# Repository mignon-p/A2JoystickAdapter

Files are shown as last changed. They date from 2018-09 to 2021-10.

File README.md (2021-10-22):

# Apple II Joystick Adapter

This small board lets you plug a 16-pin joystick into the external
9-pin joystick port on the Apple IIe.  Although the Apple IIe has an
internal 16-pin joystick port, I found that the connector on my
joystick was too big to fit through any of the holes on the back of
the IIe.  So, I created this adapter to let me plug it in externally.

This adapter could also be useful for the Apple IIc, which does not
have a 16-pin joystick port at all, although I have not tested it on a
IIc.

* [View schematic](doc/schematic.pdf)
* [View PCB][41]

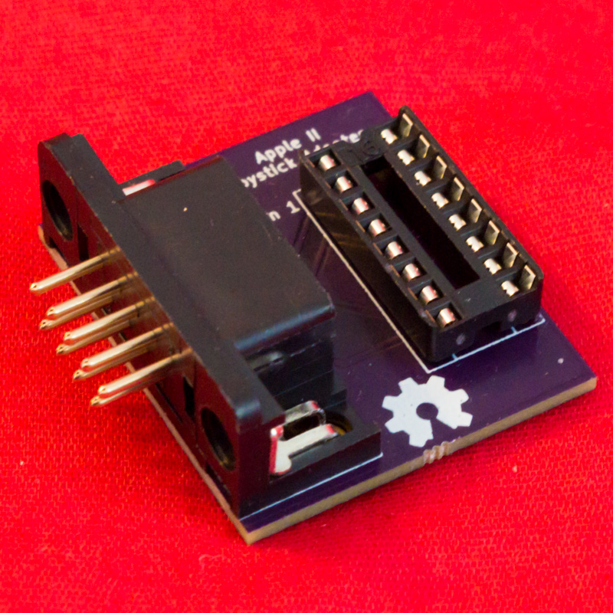
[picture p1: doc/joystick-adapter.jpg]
Joystick Adapter


## Bill of Materials

* [Right-angle male DE-9 connector][1]
* [16-pin DIP socket][2]

I found it necessary to remove the hex screws from the DE-9 connector,
because they prevented it from mating with the connector on the Apple
IIe.

## Ordering the Board

You can order this board [directly from OSH Park][40] without needing
to upload anything.

If you want to modify the design, the source is provided in
[KiCad][83] format.

## License

This project is licensed under [CC-BY-SA 4.0][10].

The symbol and footprint for the DE-9 connector are from
[the official KiCad 5 library][8] ([CC-BY-SA 4.0 with exception][9]).

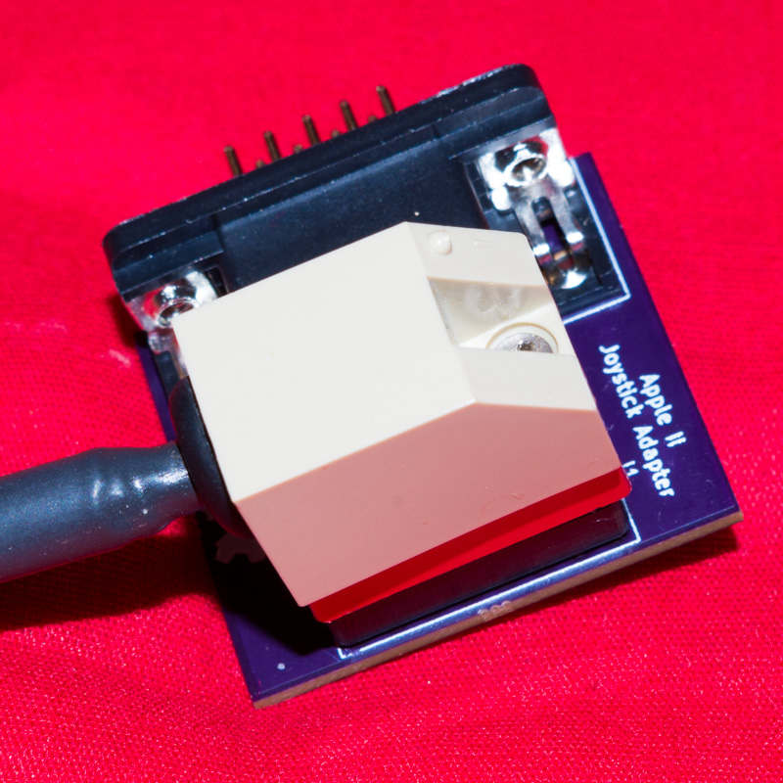
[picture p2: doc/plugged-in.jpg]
Plugging in the joystick


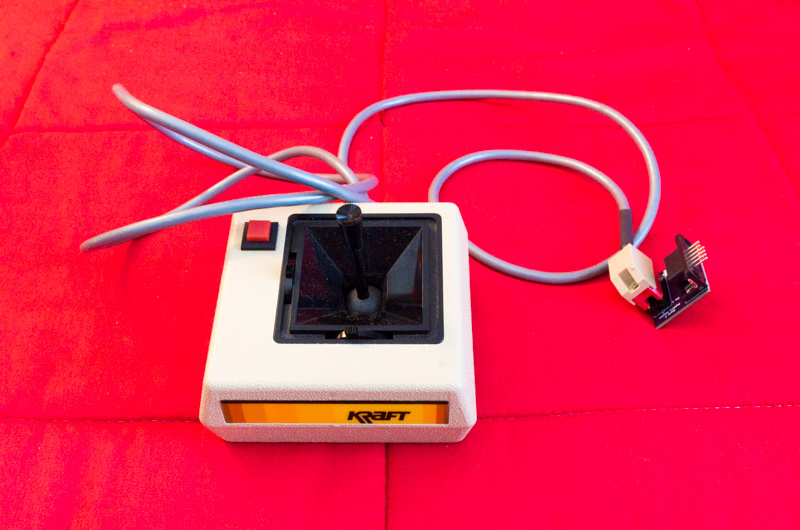
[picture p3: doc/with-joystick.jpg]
Adapter with joystick


[1]: https://www.digikey.com/product-detail/en/assmann-wsw-components/A-DS-09-A-KG-T2S/AE10968-ND/1241804
[2]: https://www.digikey.com/product-detail/en/assmann-wsw-components/A-16-LC-TT/AE9992-ND/821746
[8]: https://github.com/KiCad/kicad-symbols/blob/master/Connector.lib
[9]: https://forum.kicad.info/t/kicad-library-licensing/7856
[10]: https://creativecommons.org/licenses/by-sa/4.0/legalcode
[40]: https://oshpark.com/shared_projects/WuNA7JH0
[41]: https://eyrie.io/board/068ea680987149dfb0afcb60a86e0048
[83]: http://kicad.org/

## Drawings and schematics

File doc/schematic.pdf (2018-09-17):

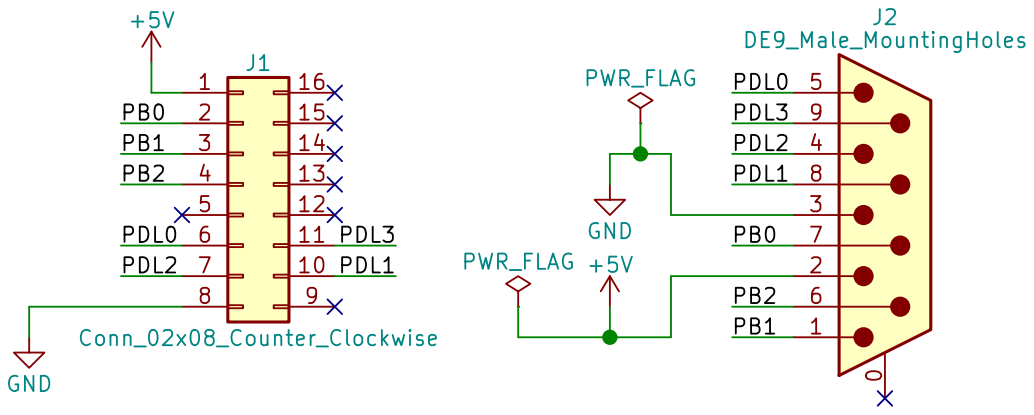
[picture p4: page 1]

File: Joystick.sch Sheet: / Patrick Pelletier

Id: 1/1 Title: 16-pin to 9-pin joystick adapter for Apple II

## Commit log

2018-09-05 Initial commit.
    [Joystick.kicad_pcb, Joystick.sch]
2018-09-05 Add DE-9 from KiCad 5.0 library.
2018-09-05 I need the version with mounting holes.
2018-09-05 Draw schematic.
    [Joystick.sch]
2018-09-05 Footprint with mounting holes.
    I plan to use:
    https://www.digikey.com/product-detail/en/assmann-wsw-components/A-DS-09-A-KG-T2S/AE10968-ND/1241804
2018-09-05 Associate footprints.
    [Joystick.sch]
2018-09-05 Place footprints.
    [Joystick.kicad_pcb]
2018-09-05 Draw tracks and zones.
    [Joystick.kicad_pcb]
2018-09-05 Add text on silkscreen.
    [Joystick.kicad_pcb]
2018-09-05 Remove the unused DE-9 connector without mounting holes.
2018-09-17 Fill in date and revision for schematic.
    [Joystick.sch]
2018-09-17 Change library version to 2.3.
    KiCad 4.0.7 doesn't seem to mind being given a version 2.4 library,
    but eyrie.io doesn't accept it.
2021-10-22 Link to kicad.org
    https://forum.kicad.info/t/warning-avoid-all-links-to-kicad-pcb-org-use-kicad-org/31521
